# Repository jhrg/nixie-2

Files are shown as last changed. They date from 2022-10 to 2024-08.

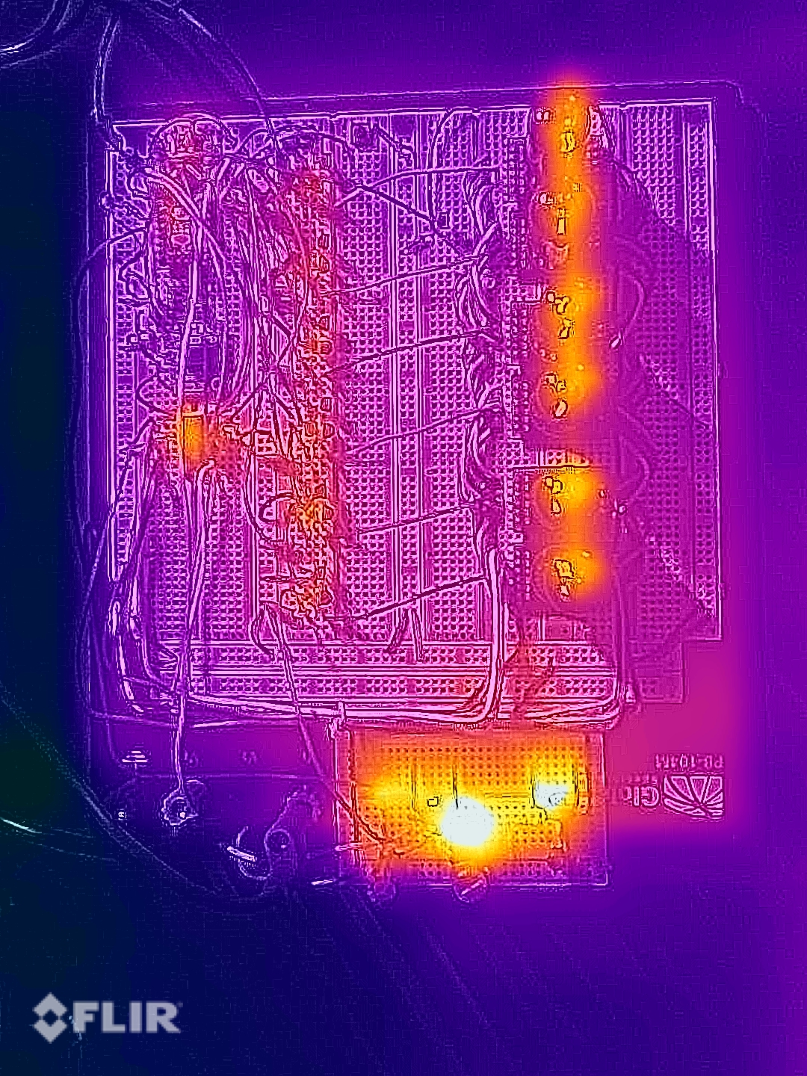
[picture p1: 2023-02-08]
docs/Nixie_FLIR_Pictures/Top_view_1.JPG

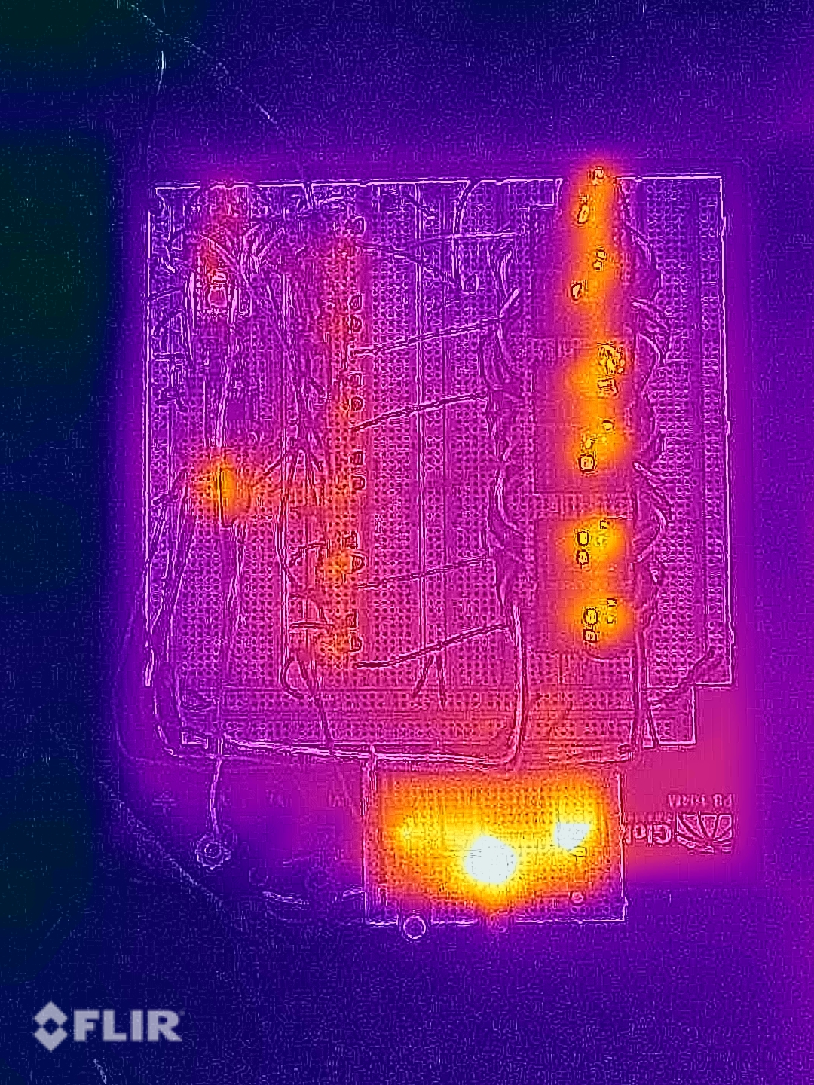
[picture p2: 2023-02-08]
docs/Nixie_FLIR_Pictures/Top_view_3.JPG

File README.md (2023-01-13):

Nixie clock code

10/1/22

The current version of this clock software is 0.1.0

A Nixie tube clock using Z573M tubes and a K155N?1 BCD to decimal driver.

This will use multiplexing to drive four Z573M tubes using one K155N?1 chip.

| Timer output | Arduino output	| Chip pin | Pin name |
|---|---|---|---|
| OC0A	 | 6	 | 12	 | PD6 |
| OC0B	 | 5	 | 11	 | PD5 |
| OC1A	 | 9	 | 15	 | PB1 |
| OC1B	 | 10	 | 16	 | PB2 |
| OC2A	 | 11	 | 17	 | PB3 |
| OC2B	 | 3	 | 5	 | PD3 |

*https://docs.arduino.cc/tutorials/generic/secrets-of-arduino-pwm

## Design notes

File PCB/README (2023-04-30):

What's here?

Z573M-tube is a breakout board for the Z57xM nixie tubes.

breakout-boards are KiCAD footprints for the Adafruit DS3231, BMP-180/280
and the exixe IN-14N nixie tube board.

nixies-2.1 has the KiCAD design files for the nixie-2.1 board

nixie-footprints.pretty holds a number of KiCAD footprints for the
nixie-2.1 PCB.

nixie-tube-clock-2.1.kicad_sym holds (most of) the symbols used by the
nixies-2.1 board.

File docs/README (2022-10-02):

Images from a scope showing the affect (good) of adding a 220K
resistor to the anode switching circuit. This decresed the time to the
off state from ~260us to 172us. It's hard to know if this is really an
improvement since the Anode voltage drops below Vm pretty fast in
either case. But, since the voltage drops to zero in 172us, that can
be the blanking interval. Since it looks like the anode voltage drops
below 100 in about 100us, might try that for the blanking interval.

The pictures are

Anode_10x_with_220k.png: The anode voltage with the 220k shunt resistor
Anode_10x_wo_220k.png: The anode voltage without the 220k shunt resistor

Anode_on_with_1466us.png: Measuring the time the anode is on when the
code uses a on delay time of 1466us

Anode_blanking.png: Measuring the time to turn the anode off, blanking
time wa 200us and this is with the 220K resistor

Anode_switch_MPSA42_base.png: What is looks like at the base of the
MPSA42 where the Arduino triggers the Anode, without the 220K shunt on
the anode.

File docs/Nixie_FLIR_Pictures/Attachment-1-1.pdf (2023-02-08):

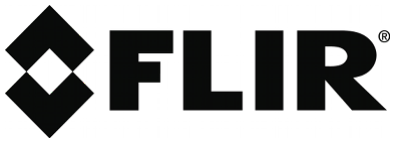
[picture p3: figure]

# PDF document

## Whole prototype top view

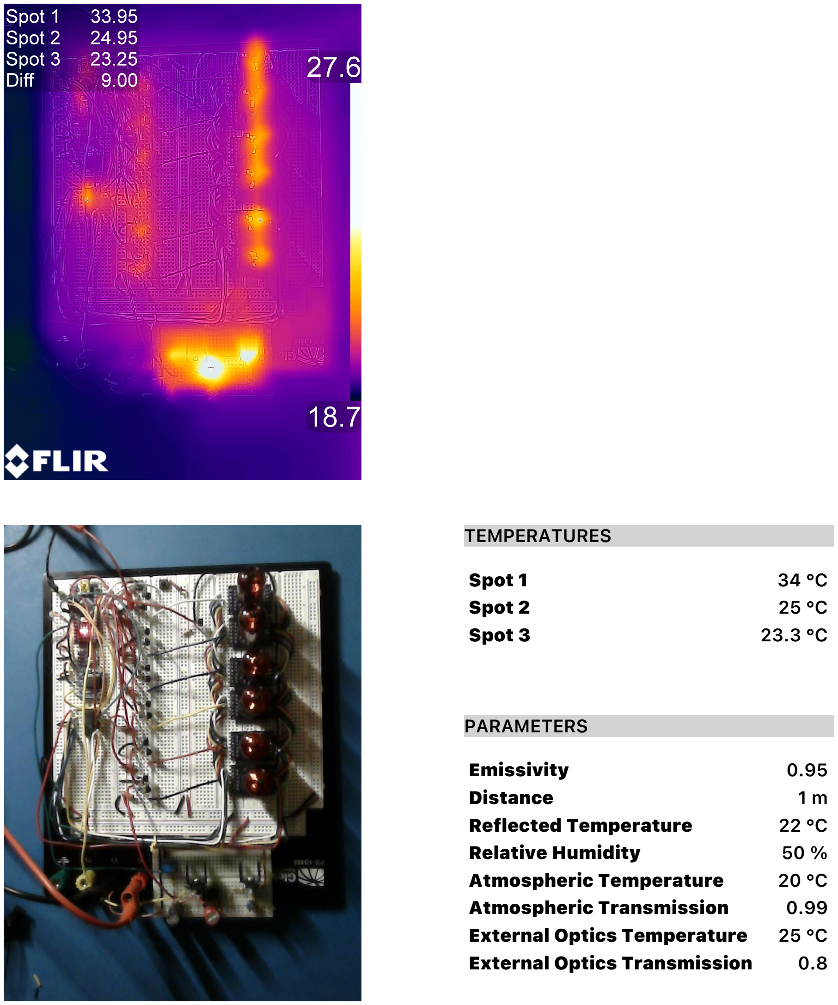
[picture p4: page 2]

TEMPERATURES

Spot 1 | 34 ℃
Spot 2 | 25 ℃
Spot 3 | 23.3 ℃

PARAMETERS

Emissivity | 0.95
Distance | 1 m
Reflected Temperature | 22 ℃
Relative Humidity | 50 %
Atmospheric Temperature | 20 ℃
Atmospheric Transmission | 0.99
External Optics Temperature | 25 ℃
External Optics Transmission | 0.8

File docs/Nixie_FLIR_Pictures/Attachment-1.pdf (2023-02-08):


# PDF document

## HV PS Close up

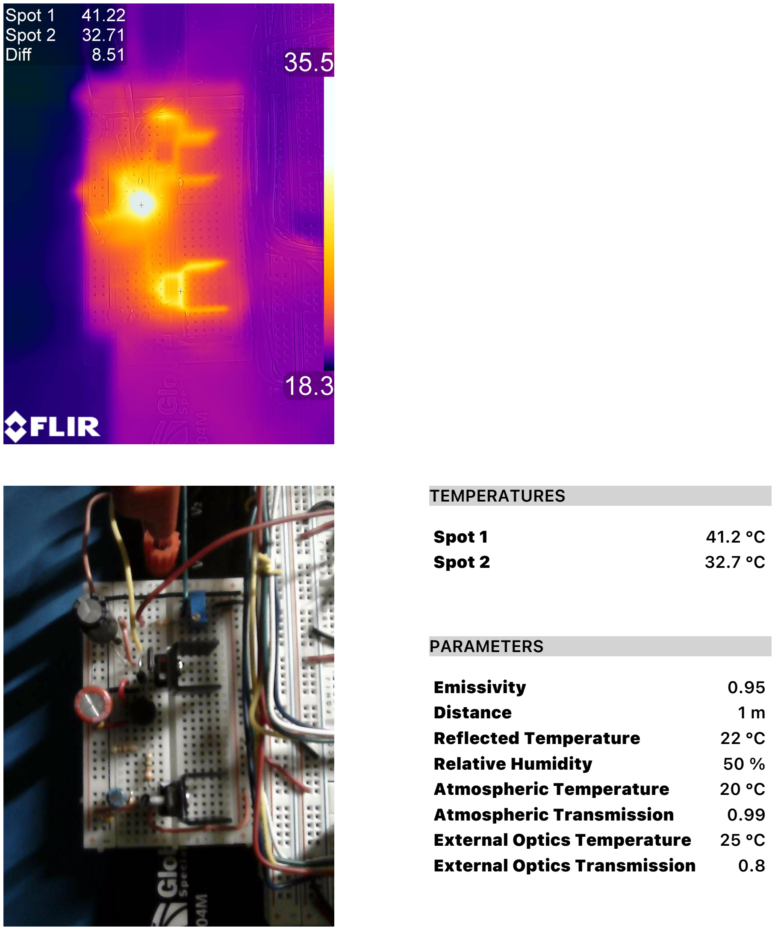
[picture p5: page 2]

TEMPERATURES

Spot 1 | 41.2 ℃
Spot 2 | 32.7 ℃

PARAMETERS

Emissivity | 0.95
Distance | 1 m
Reflected Temperature | 22 ℃
Relative Humidity | 50 %
Atmospheric Temperature | 20 ℃
Atmospheric Transmission | 0.99
External Optics Temperature | 25 ℃
External Optics Transmission | 0.8

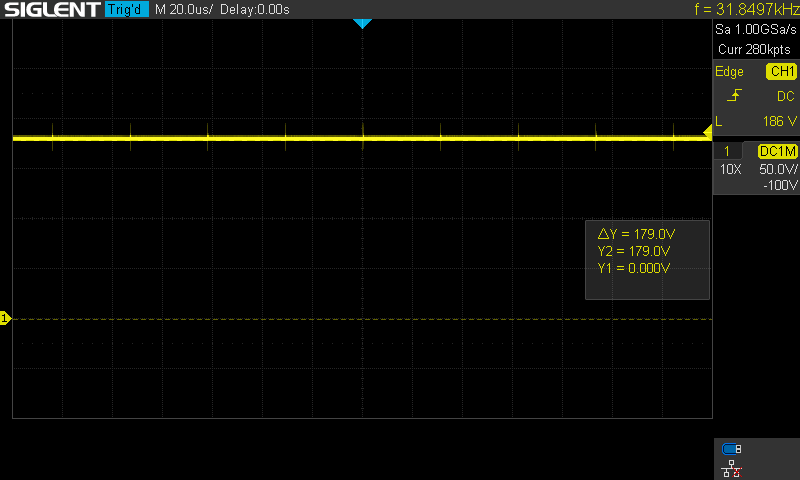
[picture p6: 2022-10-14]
docs/AVR_HV_PS/AVR_HV_PS_32kHz_no_load_10%D.png

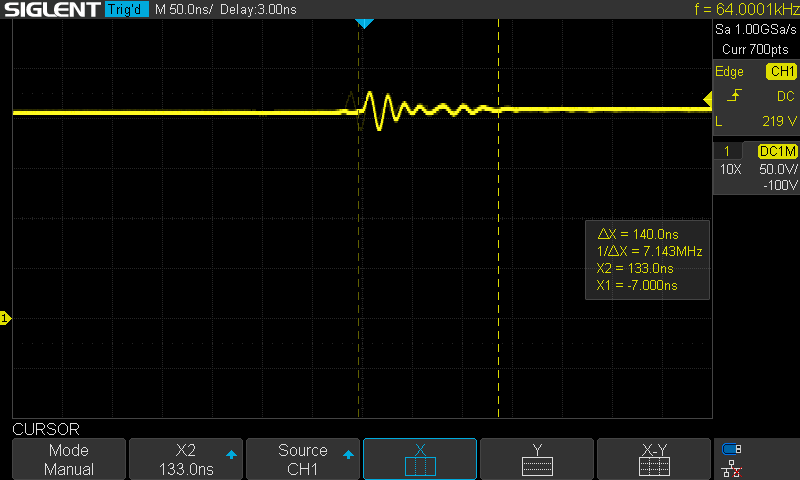
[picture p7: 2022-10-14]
docs/AVR_HV_PS/Ripple_at_64kHz.png

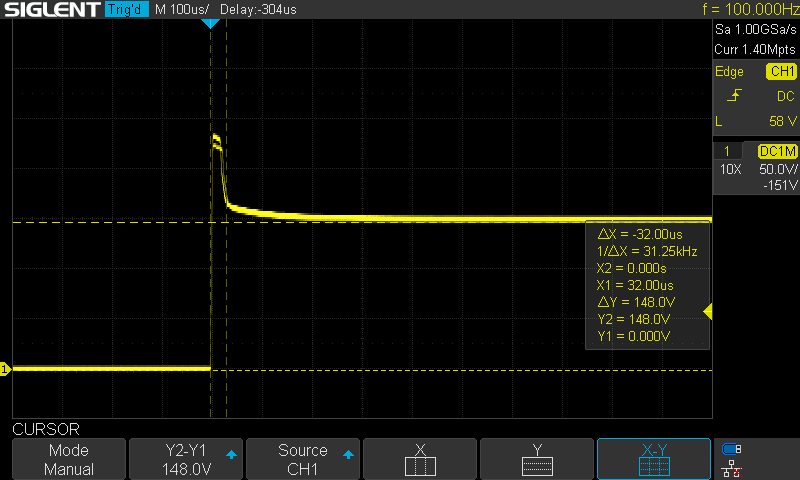
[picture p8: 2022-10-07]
docs/Ionization_time/100Hz_15k_200v_tube_voltage.png

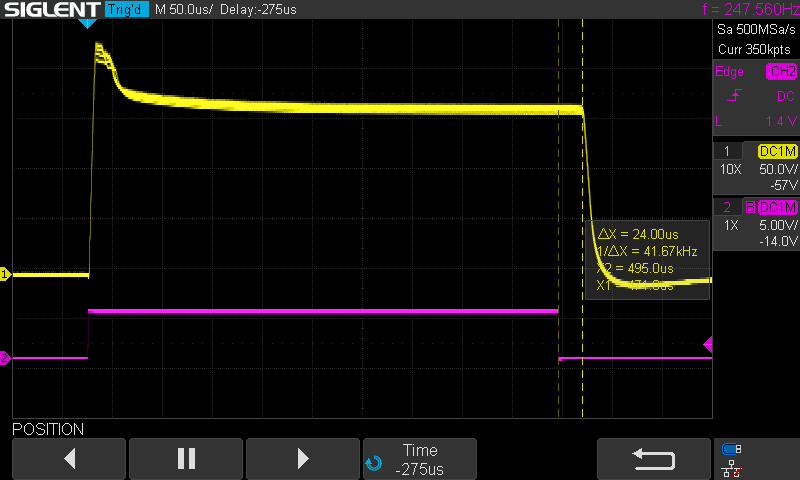
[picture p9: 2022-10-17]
docs/Anode_shunt_resistor/Tube_off_delay_24uS_with_anode_res.png

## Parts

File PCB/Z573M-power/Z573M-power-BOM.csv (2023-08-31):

Id | Designator | Footprint | Quantity | Designation | Supplier and ref
1 | H3,H2,H1 | MountingHole_3mm | 3 | MountingHole
2 | J2 | CONN3_OSTVN03A150_OST | 1 | Conn_3_screw_OSTVN03A150
3 | C4 | 10uF_400v_ESG106M400AH4AA | 1 | 10uF 400V
4 | R2,R3 | R_Axial_DIN0207_L6.3mm_D2.5mm_P7.62mm_Horizontal | 2 | 330
5 | R4 | R_Axial_DIN0207_L6.3mm_D2.5mm_P7.62mm_Horizontal | 1 | 220
6 | C6,C3,C2 | C_Disc_D5.0mm_W2.5mm_P5.00mm | 3 | 0.1uF 50V
7 | CR1 | MUR160G | 1 | MUR160G
8 | C1 | CP_Radial_D10.0mm_P5.00mm | 1 | 470uF 25V
9 | U1 | TO-220-3_Vertical | 1 | LM317_TO-220
10 | R6 | 10k_Trimmer_PV36W103C01B00 | 1 | 10K_Trimmer
11 | D3 | BZT3C240 | 1 | BZT3C240
12 | R7,R5 | R_Axial_DIN0207_L6.3mm_D2.5mm_P7.62mm_Horizontal | 2 | 390K
13 | F1 | AHRF050_30v_500mA_polyfuse | 1 | 30V 500mA
14 | D1 | D_DO-41_SOD81_P10.16mm_Horizontal | 1 | 1N5819
15 | J1 | BarrelJack_Horizontal | 1 | Barrel_Jack_Switch
16 | HS1,HS2 | AVVID-577202B-00000G | 2 | Heatsink
17 | Q1 | TO-220-3_Vertical | 1 | IRF730 TO220-3
18 | L1 | L_Radial_D7.8mm_P5.00mm_Fastron_07HCP | 1 | 200uH 1A 450m
19 | J3 | CONN_OSTVN02A150_OST | 1 | Conn_2_screw_OSTVN02A150
20 | Q2 | TO-92_HandSolder | 1 | ZTX857
21 | D2 | D_A-405_P7.62mm_Horizontal | 1 | 1N4002
22 | R1 | R_Axial_DIN0207_L6.3mm_D2.5mm_P7.62mm_Horizontal | 1 | 1M
23 | C5 | 1.0uF_160V_CAPPRD200W50D525H1250 | 1 | 1.0uF 160V

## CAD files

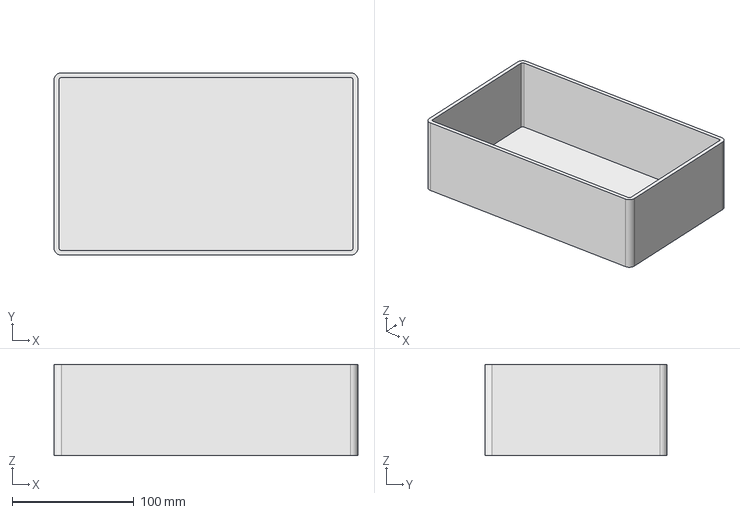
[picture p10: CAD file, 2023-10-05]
enclosure/box_2.FCStd
250.0 x 150.0 x 75.0 mm

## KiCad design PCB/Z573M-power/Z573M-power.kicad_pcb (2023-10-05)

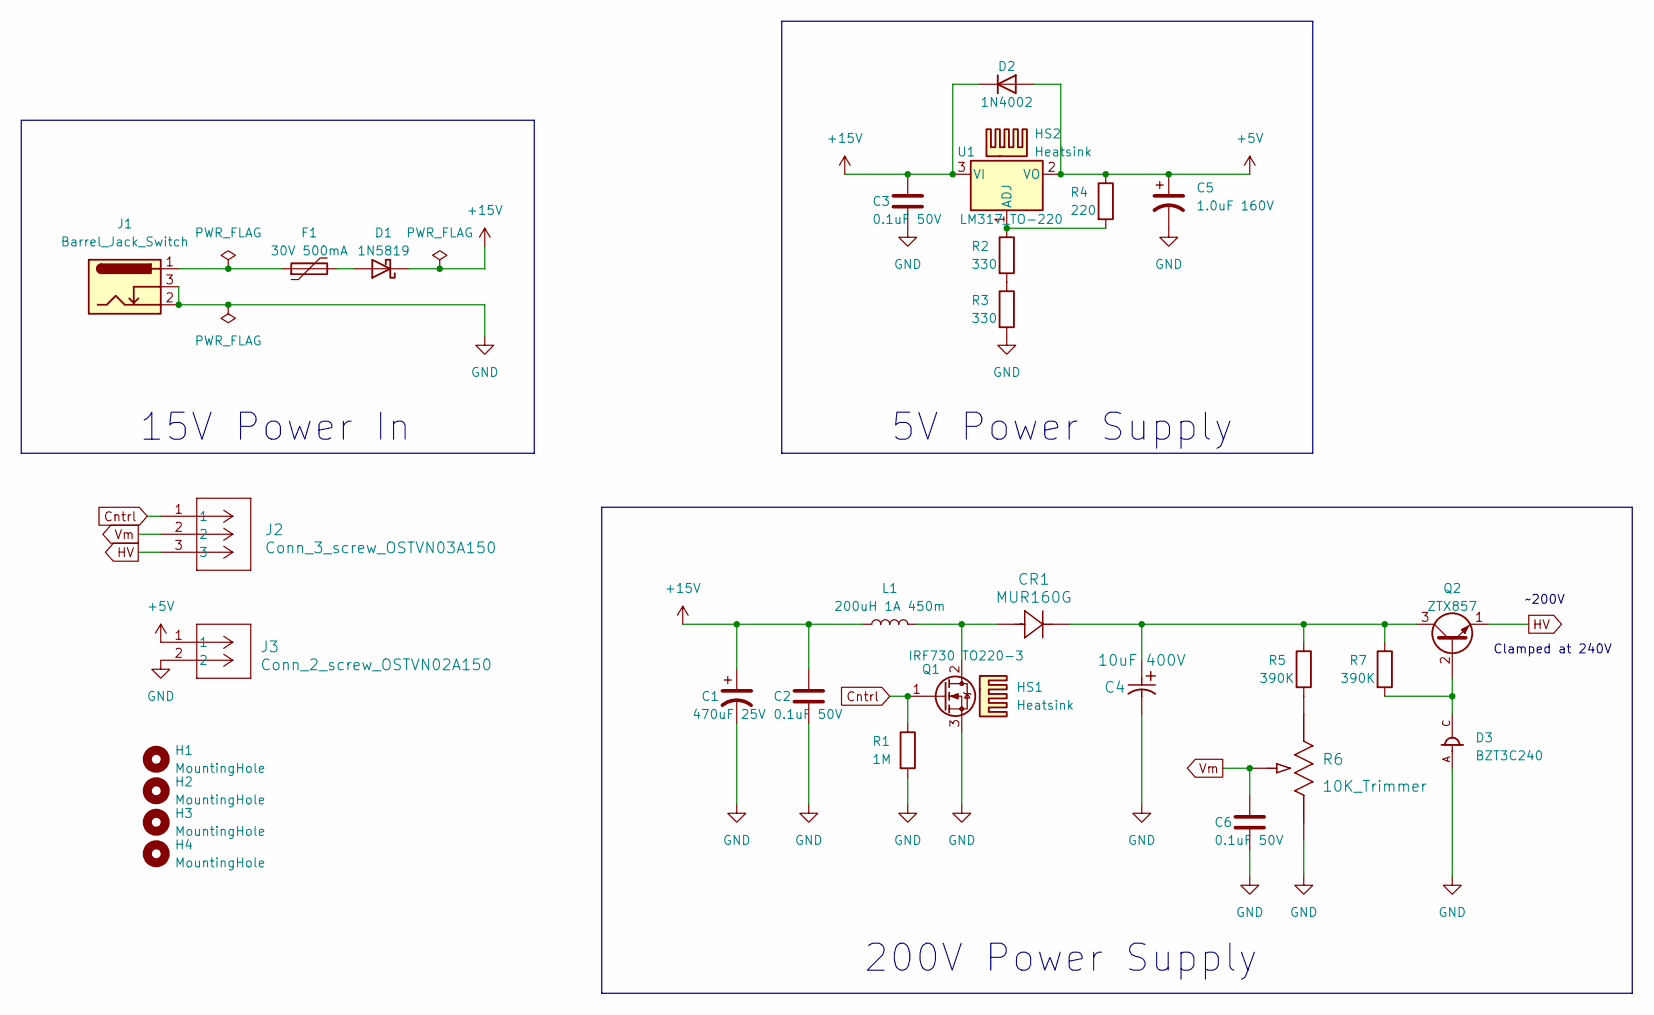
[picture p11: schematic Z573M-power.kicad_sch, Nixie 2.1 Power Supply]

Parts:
C1: 470uF 25V; CP_Radial_D10.0mm_P5.00mm
C2, C3, C6: 0.1uF 50V; C_Disc_D5.0mm_W2.5mm_P5.00mm
C4: 10uF 400V; 10uF_400v_ESG106M400AH4AA
C5: 1.0uF 160V; 1.0uF_160V_CAPPRD200W50D525H1250
CR1: MUR160G
D1: 1N5819; D_DO-41_SOD81_P10.16mm_Horizontal
D2: 1N4002; D_A-405_P7.62mm_Horizontal
D3: BZT3C240
F1: 30V 500mA; AHRF050_30v_500mA_polyfuse
H1, H2, H3, H4: MountingHole; MountingHole_3mm
HS1, HS2: Heatsink; AVVID-577202B-00000G
J1: Barrel_Jack_Switch; BarrelJack_Horizontal
J2: Conn_3_screw_OSTVN03A150; CONN3_OSTVN03A150_OST
J3: Conn_2_screw_OSTVN02A150; CONN_OSTVN02A150_OST
L1: 200uH 1A 450m; L_Radial_D7.8mm_P5.00mm_Fastron_07HCP
Q1: IRF730 TO220-3; TO-220-3_Vertical
Q2: ZTX857; TO-92_HandSolder
R1: 1M; R_Axial_DIN0207_L6.3mm_D2.5mm_P7.62mm_Horizontal
R2, R3: 330; R_Axial_DIN0207_L6.3mm_D2.5mm_P7.62mm_Horizontal
R4: 220; R_Axial_DIN0207_L6.3mm_D2.5mm_P7.62mm_Horizontal
R5, R7: 390K; R_Axial_DIN0207_L6.3mm_D2.5mm_P7.62mm_Horizontal
R6: 10K_Trimmer; 10k_Trimmer_PV36W103C01B00
U1: LM317_TO-220; TO-220-3_Vertical

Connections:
+5V: C5.1, D2.2 (A), J3.1, R4.1, U1.2 (VO)
+15V: C1.1, C2.1, C3.1, D1.1 (K), D2.1 (K), L1.1, U1.3 (VI)
Cntrl: J2.1, Q1.1 (G), R1.1
GND: C1.2, C2.2, C3.2, C4.2, C5.2, C6.2, D3.A, J1.2, J1.3, J3.2, Q1.3 (S), R1.2, R3.2, R6.1
HV: J2.3, Q2.1 (E)
unnamed: D1.2 (A), F1.2
unnamed: F1.1, J1.1
unnamed: CR1.2, L1.2, Q1.2 (D)
unnamed: D3.C, Q2.2 (B), R7.2
unnamed: C4.1, CR1.1, Q2.3 (C), R5.1, R7.1
unnamed: R2.2, R3.1
unnamed: R5.2, R6.3
unnamed: R2.1, R4.2, U1.1 (ADJ)
Vm: C6.1, J2.2, R6.2

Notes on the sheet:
5V Power Supply
~200V
200V Power Supply
15V Power In
Clamped at 240V

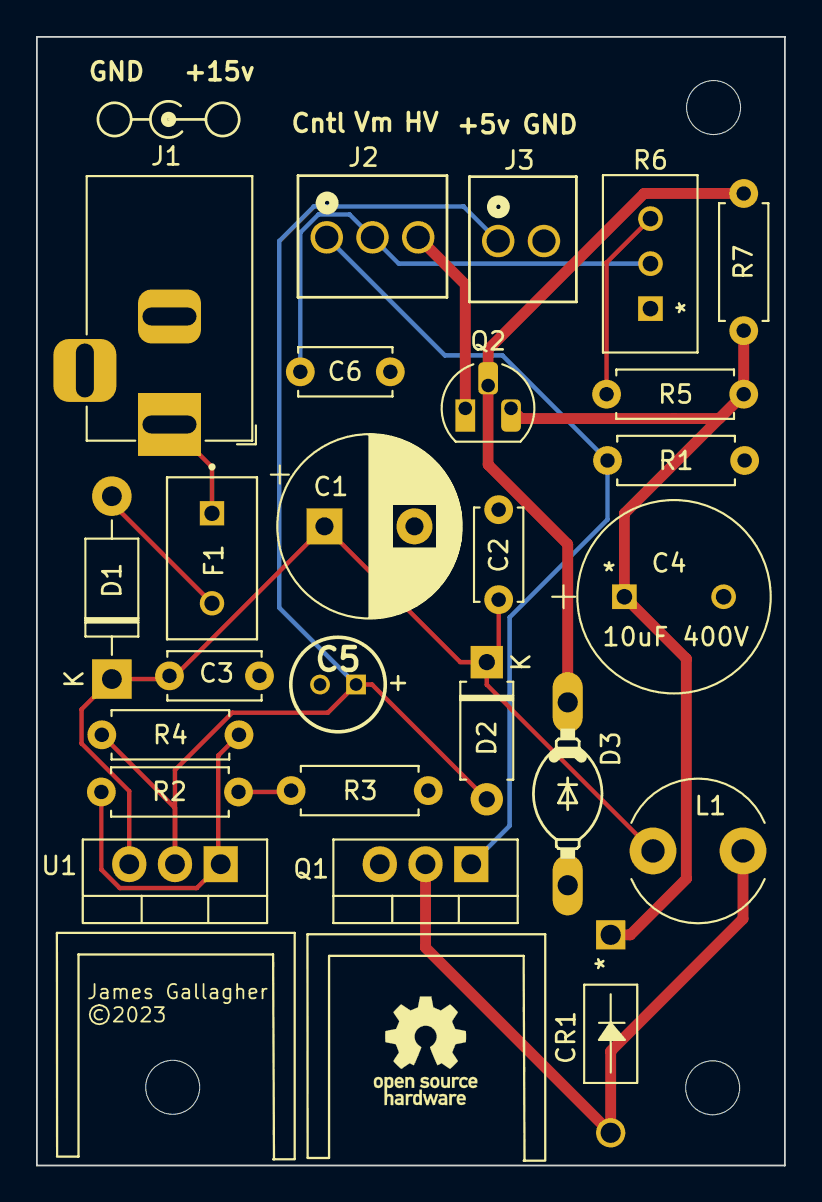
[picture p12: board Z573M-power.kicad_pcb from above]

Board: 2 copper layers, 41.6 x 62.7 mm, 30 parts (0 on the bottom side), 14 nets.

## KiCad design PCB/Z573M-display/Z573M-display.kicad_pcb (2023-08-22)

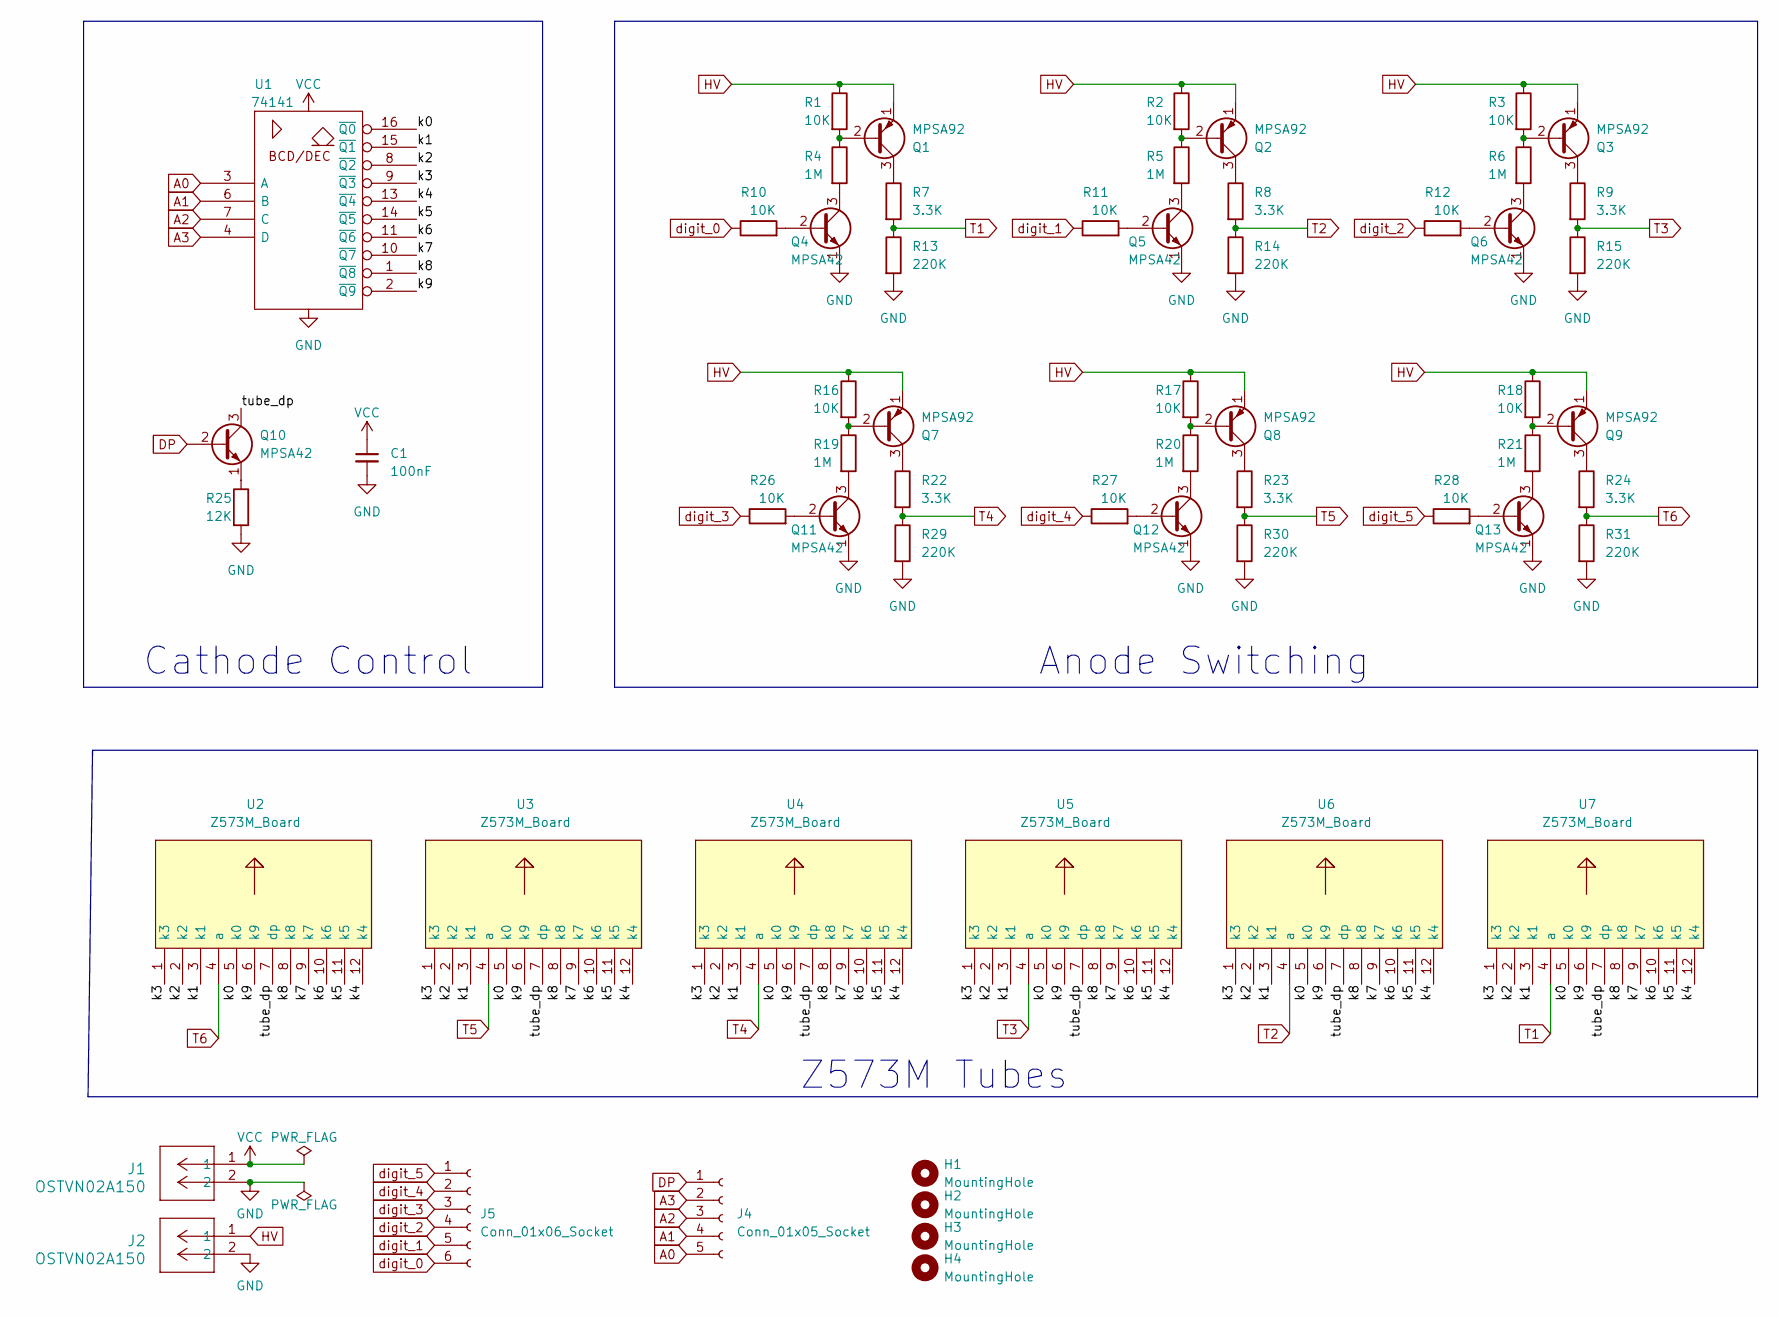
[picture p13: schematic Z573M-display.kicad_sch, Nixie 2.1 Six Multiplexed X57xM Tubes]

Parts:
C1: 100nF; C_Disc_D4.7mm_W2.5mm_P5.00mm
H1, H2, H3, H4: MountingHole; MountingHole_3mm
J1, J2: OSTVN02A150; CONN_OSTVN02A150_OST
J4: Conn_01x05_Socket; PinHeader_1x05_P2.54mm_Horizontal
J5: Conn_01x06_Socket; PinHeader_1x06_P2.54mm_Horizontal
Q1, Q2, Q3, Q7, Q8, Q9: MPSA92; TO-92_HandSolder
Q4, Q5, Q6, Q10, Q11, Q12, Q13: MPSA42; TO-92_HandSolder
R1, R2, R3, R10, R11, R12, R16, R17, R18, R26, R27, R28: 10K; R_Axial_DIN0207_L6.3mm_D2.5mm_P7.62mm_Horizontal
R4, R5, R6, R19, R20, R21: 1M; R_Axial_DIN0207_L6.3mm_D2.5mm_P7.62mm_Horizontal
R7, R8, R9, R22, R23, R24: 3.3K; R_Axial_DIN0207_L6.3mm_D2.5mm_P7.62mm_Horizontal
R13, R14, R15, R29, R30, R31: 220K; R_Axial_DIN0207_L6.3mm_D2.5mm_P7.62mm_Horizontal
R25: 12K; R_Axial_DIN0207_L6.3mm_D2.5mm_P7.62mm_Horizontal
U1: 74141; DIP-16_W7.62mm_Socket
U2, U3, U4, U5, U6, U7: Z573M_Board

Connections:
/k0: U1.16 (~Q0), U2.5 (k0), U3.5 (k0), U4.5 (k0), U5.5 (k0), U6.5 (k0), U7.5 (k0)
/k1: U1.15 (~Q1), U2.3 (k1), U3.3 (k1), U4.3 (k1), U5.3 (k1), U6.3 (k1), U7.3 (k1)
/k2: U1.8 (~Q2), U2.2 (k2), U3.2 (k2), U4.2 (k2), U5.2 (k2), U6.2 (k2), U7.2 (k2)
/k3: U1.9 (~Q3), U2.1 (k3), U3.1 (k3), U4.1 (k3), U5.1 (k3), U6.1 (k3), U7.1 (k3)
/k4: U1.13 (~Q4), U2.12 (k4), U3.12 (k4), U4.12 (k4), U5.12 (k4), U6.12 (k4), U7.12 (k4)
/k5: U1.14 (~Q5), U2.11 (k5), U3.11 (k5), U4.11 (k5), U5.11 (k5), U6.11 (k5), U7.11 (k5)
/k6: U1.11 (~Q6), U2.10 (k6), U3.10 (k6), U4.10 (k6), U5.10 (k6), U6.10 (k6), U7.10 (k6)
/k7: U1.10 (~Q7), U2.9 (k7), U3.9 (k7), U4.9 (k7), U5.9 (k7), U6.9 (k7), U7.9 (k7)
/k8: U1.1 (~Q8), U2.8 (k8), U3.8 (k8), U4.8 (k8), U5.8 (k8), U6.8 (k8), U7.8 (k8)
/k9: U1.2 (~Q9), U2.6 (k9), U3.6 (k9), U4.6 (k9), U5.6 (k9), U6.6 (k9), U7.6 (k9)
/tube_dp: Q10.3 (C), U2.7 (dp), U3.7 (dp), U4.7 (dp), U5.7 (dp), U6.7 (dp), U7.7 (dp)
A0: J4.5, U1.3 (A)
A1: J4.4, U1.6 (B)
A2: J4.3, U1.7 (C)
A3: J4.2, U1.4 (D)
DP: J4.1, Q10.2 (B)
GND: C1.2, J1.2, J2.2, Q4.1 (E), Q5.1 (E), Q6.1 (E), Q11.1 (E), Q12.1 (E), Q13.1 (E), R13.2, R14.2, R15.2, R25.2, R29.2, R30.2, R31.2, U1.12 (GND)
HV: J2.1, Q1.1 (E), Q2.1 (E), Q3.1 (E), Q7.1 (E), Q8.1 (E), Q9.1 (E), R1.1, R2.1, R3.1, R16.1, R17.1, R18.1
unnamed: Q1.2 (B), R1.2, R4.1
unnamed: Q1.3 (C), R7.1
unnamed: Q2.2 (B), R2.2, R5.1
unnamed: Q2.3 (C), R8.1
unnamed: Q3.2 (B), R3.2, R6.1
unnamed: Q3.3 (C), R9.1
unnamed: Q4.2 (B), R10.2
unnamed: Q4.3 (C), R4.2
unnamed: Q5.2 (B), R11.2
unnamed: Q5.3 (C), R5.2
unnamed: Q6.2 (B), R12.2
unnamed: Q6.3 (C), R6.2
unnamed: Q7.2 (B), R16.2, R19.1
unnamed: Q7.3 (C), R22.1
unnamed: Q8.2 (B), R17.2, R20.1
unnamed: Q8.3 (C), R23.1
unnamed: Q9.2 (B), R18.2, R21.1
unnamed: Q9.3 (C), R24.1
unnamed: Q10.1 (E), R25.1
unnamed: Q11.2 (B), R26.2
unnamed: Q11.3 (C), R19.2
unnamed: Q12.2 (B), R27.2
unnamed: Q12.3 (C), R20.2
unnamed: Q13.2 (B), R28.2
unnamed: Q13.3 (C), R21.2
T1: R7.2, R13.1, U7.4 (a)
T2: R8.2, R14.1, U6.4 (a)
T3: R9.2, R15.1, U5.4 (a)
T4: R22.2, R29.1, U4.4 (a)
T5: R23.2, R30.1, U3.4 (a)
T6: R24.2, R31.1, U2.4 (a)
VCC: C1.1, J1.1, U1.5 (VCC)
digit_0: J5.6, R10.1
digit_1: J5.5, R11.1
digit_2: J5.4, R12.1
digit_3: J5.3, R26.1
digit_4: J5.2, R27.1
digit_5: J5.1, R28.1

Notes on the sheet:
Z573M Tubes
Anode Switching
Cathode Control

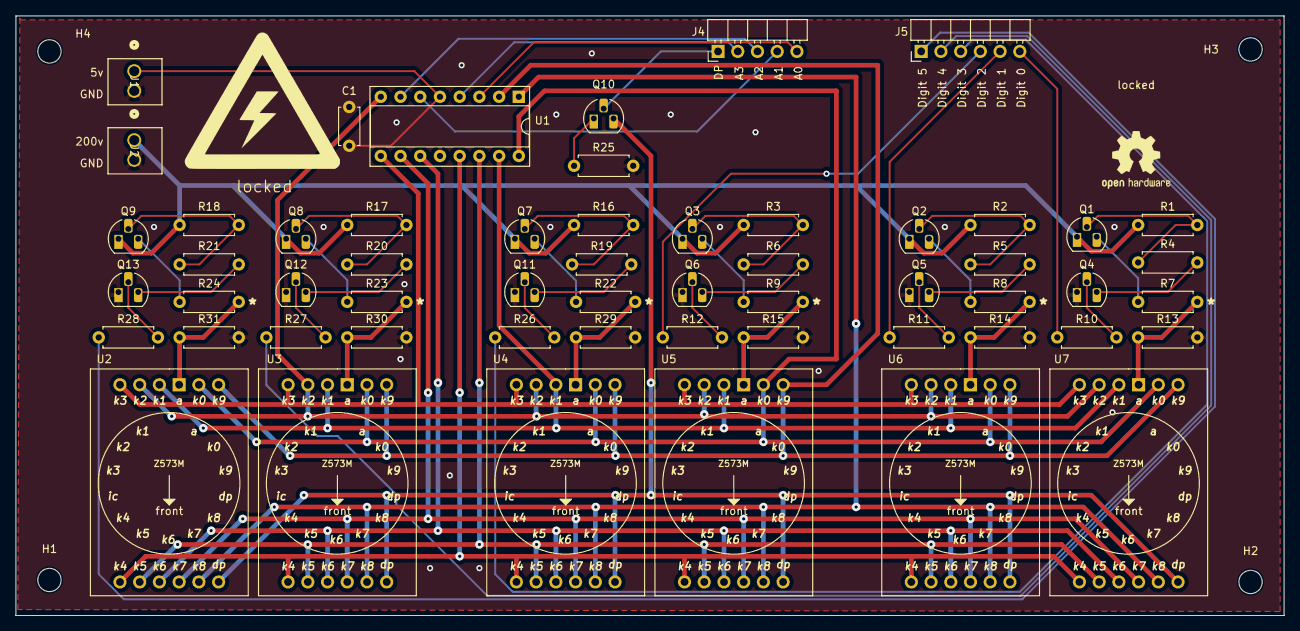
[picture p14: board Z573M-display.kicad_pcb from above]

Board: 2 copper layers, 163.3 x 77.2 mm, 60 parts (0 on the bottom side), 56 nets.

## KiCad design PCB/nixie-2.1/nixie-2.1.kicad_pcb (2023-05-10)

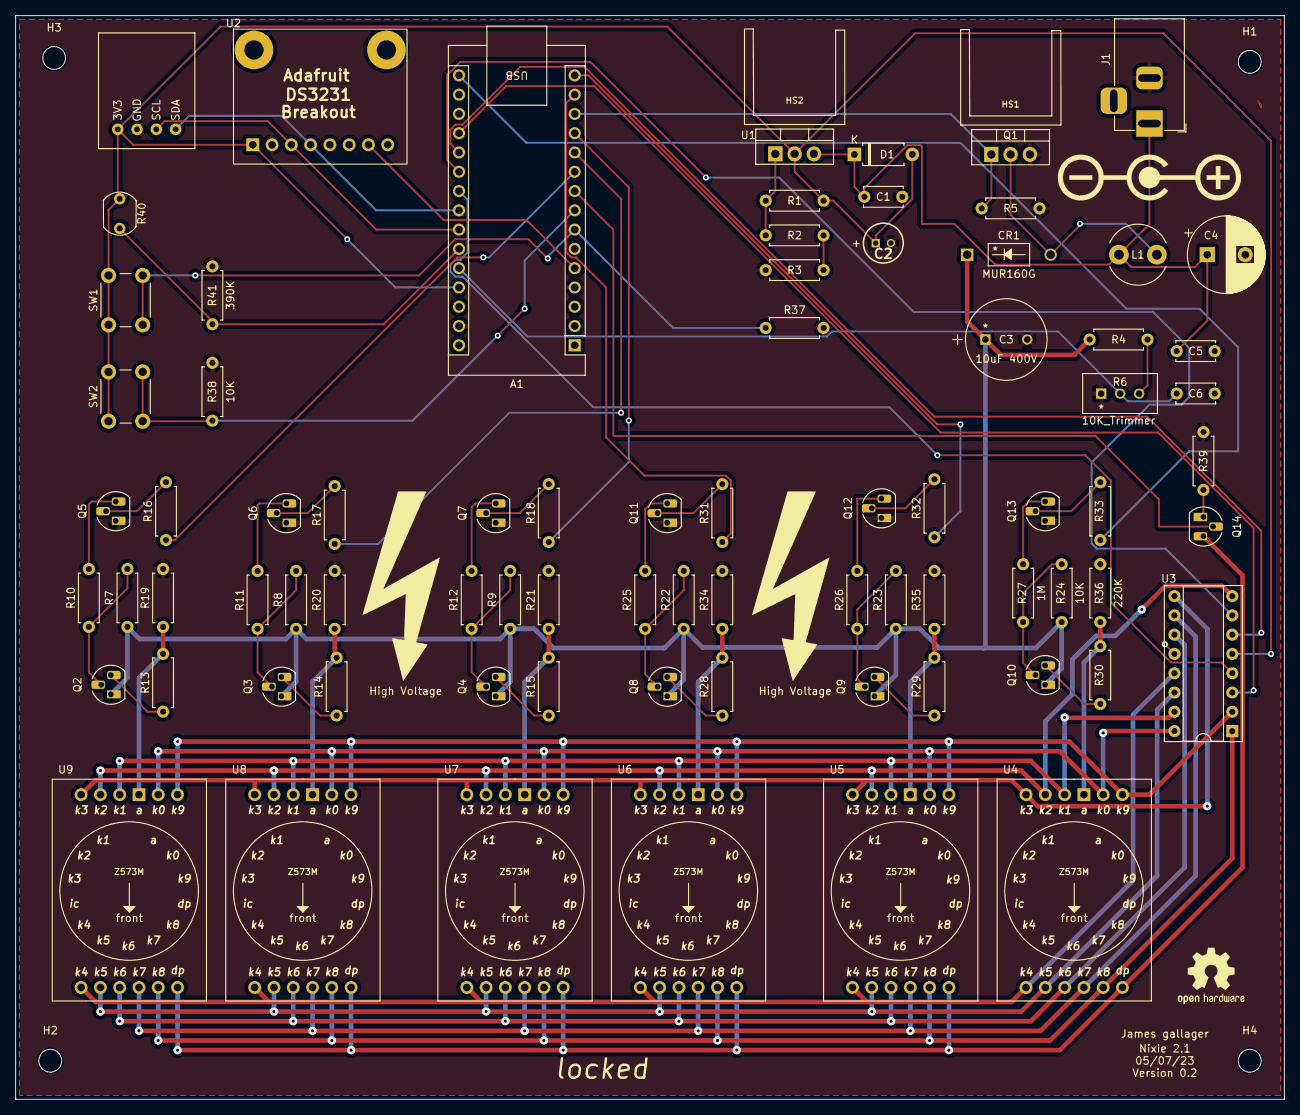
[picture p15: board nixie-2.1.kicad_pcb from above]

Board: 2 copper layers, 167.1 x 142.7 mm, 84 parts (0 on the bottom side), 69 nets.

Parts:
A1: Arduino_Nano_v3.x; Arduino_Nano
C1, C5, C6: 0.1uF 50V; C_Disc_D5.0mm_W2.5mm_P5.00mm
C2: 1.0uF 160V; 1.0uF_160V_CAPPRD200W50D525H1250
C3: 10uF 400V; ESG475M400AH2AA
C4: 470uF 25V; CP_Radial_D10.0mm_P5.00mm
CR1: MUR160G
D1: 1N4002; D_A-405_P7.62mm_Horizontal
H1, H2, H3, H4: MountingHole; MountingHole_3mm
HS1, HS2: Heatsink; AVVID-577202B-00000G
J1: Barrel_Jack_Switch; BarrelJack_Horizontal
L1: 200uH 1A 450m; L_Radial_D7.8mm_P5.00mm_Fastron_07HCP
Q1: IRF730 TO220-3; TO-220-3_Vertical
Q2, Q3, Q4, Q8, Q9, Q10: MPSA92; TO-92_HandSolder
Q5, Q6, Q7, Q11, Q12, Q13, Q14: MPSA42; TO-92_HandSolder
R1: 220; R_Axial_DIN0207_L6.3mm_D2.5mm_P7.62mm_Horizontal
R2, R3: 330; R_Axial_DIN0207_L6.3mm_D2.5mm_P7.62mm_Horizontal
R4, R41: 390K; R_Axial_DIN0207_L6.3mm_D2.5mm_P7.62mm_Horizontal
R5, R10, R11, R12, R25, R26, R27: 1M; R_Axial_DIN0207_L6.3mm_D2.5mm_P7.62mm_Horizontal
R6: 10K_Trimmer; PV36W103C01B00
R7, R8, R9, R16, R17, R18, R22, R23, R24, R31, R32, R33, R37, R38: 10K; R_Axial_DIN0207_L6.3mm_D2.5mm_P7.62mm_Horizontal
R13, R14, R15, R28, R29, R30: 3.3K; R_Axial_DIN0207_L6.3mm_D2.5mm_P7.62mm_Horizontal
R19, R20, R21, R34, R35, R36: 220K; R_Axial_DIN0207_L6.3mm_D2.5mm_P7.62mm_Horizontal
R39: 12K; R_Axial_DIN0207_L6.3mm_D2.5mm_P7.62mm_Horizontal
R40: R_Photo; R_LDR_5.1x4.3mm_P3.9mm_Vertical
SW1, SW2: SW_Push; SW_PUSH_6mm
U1: LM317_TO-220; TO-220-3_Vertical
U2: Adafruit_DS3231_breakout
U3: 74141; DIP-16_W7.62mm_Socket
U4, U5, U6, U7, U8, U9: Z573M_Board
U10: BMP180_breakout; BMP280_bb

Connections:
1s_pulse: A1.5 (D2), U2.7 (SQW)
+5V: A1.27 (+5V), C2.1, D1.2 (A), R1.1, R40.1, SW1.1, SW2.1, U1.2 (VO), U2.1 (Vin), U3.5 (VCC), U10.1 (Vin)
+15V: C1.1, C4.1, C5.1, D1.1 (K), J1.1, L1.1, U1.3 (VI)
/Nixies 2.1 Display/k0: U3.16 (~Q0), U4.5 (k0), U5.5 (k0), U6.5 (k0), U7.5 (k0), U8.5 (k0), U9.5 (k0)
/Nixies 2.1 Display/k1: U3.15 (~Q1), U4.3 (k1), U5.3 (k1), U6.3 (k1), U7.3 (k1), U8.3 (k1), U9.3 (k1)
/Nixies 2.1 Display/k2: U3.8 (~Q2), U4.2 (k2), U5.2 (k2), U6.2 (k2), U7.2 (k2), U8.2 (k2), U9.2 (k2)
/Nixies 2.1 Display/k3: U3.9 (~Q3), U4.1 (k3), U5.1 (k3), U6.1 (k3), U7.1 (k3), U8.1 (k3), U9.1 (k3)
/Nixies 2.1 Display/k4: U3.13 (~Q4), U4.12 (k4), U5.12 (k4), U6.12 (k4), U7.12 (k4), U8.12 (k4), U9.12 (k4)
/Nixies 2.1 Display/k5: U3.14 (~Q5), U4.11 (k5), U5.11 (k5), U6.11 (k5), U7.11 (k5), U8.11 (k5), U9.11 (k5)
/Nixies 2.1 Display/k6: U3.11 (~Q6), U4.10 (k6), U5.10 (k6), U6.10 (k6), U7.10 (k6), U8.10 (k6), U9.10 (k6)
/Nixies 2.1 Display/k7: U3.10 (~Q7), U4.9 (k7), U5.9 (k7), U6.9 (k7), U7.9 (k7), U8.9 (k7), U9.9 (k7)
/Nixies 2.1 Display/k8: U3.1 (~Q8), U4.8 (k8), U5.8 (k8), U6.8 (k8), U7.8 (k8), U8.8 (k8), U9.8 (k8)
/Nixies 2.1 Display/k9: U3.2 (~Q9), U4.6 (k9), U5.6 (k9), U6.6 (k9), U7.6 (k9), U8.6 (k9), U9.6 (k9)
/Nixies 2.1 Display/tube_dp: Q14.3 (C), U4.7 (dp), U5.7 (dp), U6.7 (dp), U7.7 (dp), U8.7 (dp), U9.7 (dp)
A0: A1.19 (A0), U3.3 (A)
A1: A1.20 (A1), U3.6 (B)
A2: A1.21 (A2), U3.7 (C)
A3: A1.22 (A3), U3.4 (D)
Cntrl: A1.13 (D10), Q1.1 (G), R5.1
DP: A1.9 (D6), Q14.2 (B)
GND: A1.4 (GND), A1.29 (GND), C1.2, C2.2, C3.2, C4.2, C5.2, C6.2, J1.2, Q1.3 (S), Q5.1 (E), Q6.1 (E), Q7.1 (E), Q11.1 (E), Q12.1 (E), Q13.1 (E), R3.2, R5.2, R6.1, R19.2, R20.2, R21.2, R34.2, R35.2, R36.2, R37.2, R38.2, R39.2, R41.2, U2.2 (GND), U3.12 (GND), U10.2 (GND)
HV: C3.1, CR1.1, Q2.1 (E), Q3.1 (E), Q4.1 (E), Q8.1 (E), Q9.1 (E), Q10.1 (E), R4.1, R7.1, R8.1, R9.1, R22.1, R23.1, R24.1
unnamed: A1.25 (A6), R40.2, R41.1
unnamed: A1.7 (D4), R37.1, SW1.2
unnamed: A1.8 (D5), R38.1, SW2.2
unnamed: CR1.2, L1.2, Q1.2 (D)
unnamed: Q2.2 (B), R7.2, R10.1
unnamed: Q2.3 (C), R13.1
unnamed: Q3.2 (B), R8.2, R11.1
unnamed: Q3.3 (C), R14.1
unnamed: Q4.2 (B), R9.2, R12.1
unnamed: Q4.3 (C), R15.1
unnamed: Q5.2 (B), R16.2
unnamed: Q5.3 (C), R10.2
unnamed: Q6.2 (B), R17.2
unnamed: Q6.3 (C), R11.2
unnamed: Q7.2 (B), R18.2
unnamed: Q7.3 (C), R12.2
unnamed: Q8.2 (B), R22.2, R25.1
unnamed: Q8.3 (C), R28.1
unnamed: Q9.2 (B), R23.2, R26.1
unnamed: Q9.3 (C), R29.1
unnamed: Q10.2 (B), R24.2, R27.1
unnamed: Q10.3 (C), R30.1
unnamed: Q11.2 (B), R31.2
unnamed: Q11.3 (C), R25.2
unnamed: Q12.2 (B), R32.2
unnamed: Q12.3 (C), R26.2
unnamed: Q13.2 (B), R33.2
unnamed: Q13.3 (C), R27.2
unnamed: Q14.1 (E), R39.1
unnamed: R2.2, R3.1
unnamed: R4.2, R6.3
unnamed: R1.2, R2.1, U1.1 (ADJ)
SCL: A1.24 (A5), U2.3 (SCL), U10.3 (SCL)
SDA: A1.23 (A4), U2.4 (SDA), U10.4 (SDA)
T1: R13.2, R19.1, U9.4 (a)
T2: R14.2, R20.1, U8.4 (a)
T3: R15.2, R21.1, U7.4 (a)
T4: R28.2, R34.1, U6.4 (a)
T5: R29.2, R35.1, U5.4 (a)
T6: R30.2, R36.1, U4.4 (a)
Vm: A1.26 (A7), C6.1, R6.2
digit_0: A1.10 (D7), R16.1
digit_1: A1.11 (D8), R17.1
digit_2: A1.12 (D9), R18.1
digit_3: A1.14 (D11), R31.1
digit_4: A1.15 (D12), R32.1
digit_5: A1.16 (D13), R33.1

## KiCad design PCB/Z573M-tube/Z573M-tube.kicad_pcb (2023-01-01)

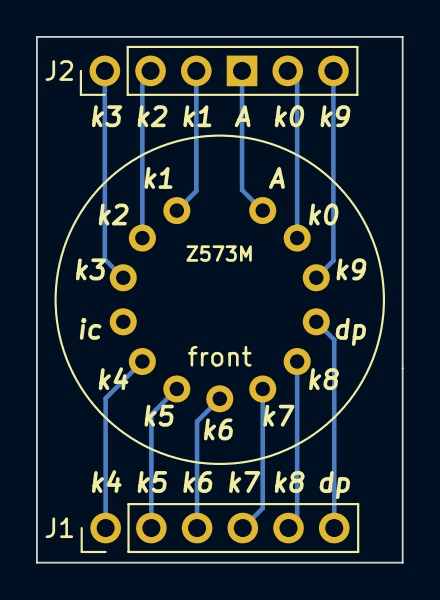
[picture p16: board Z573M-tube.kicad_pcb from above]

Board: 2 copper layers, 20.3 x 29.2 mm, 3 parts (0 on the bottom side), 12 nets.

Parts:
J1, J2: 6-pin-header; PinHeader_1x06_P2.54mm_Vertical
Version 2.0: Z57xM; Z57xM-v3-HV

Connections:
/A: J2.4, Version 2.0.13 (A)
/K0: J2.5, Version 2.0.12 (K0)
/K1: J2.3, Version 2.0.1 (K1)
/K2: J2.2, Version 2.0.2 (K2)
/K3: J2.1, Version 2.0.3 (K3)
/K4: J1.1, Version 2.0.5 (K4)
/K5: J1.2, Version 2.0.6 (K5)
/K6: J1.3, Version 2.0.7 (K6)
/K7: J1.4, Version 2.0.8 (K7)
/K8: J1.5, Version 2.0.9 (K8)
/K9: J2.6, Version 2.0.11 (K9)
/KPR: J1.6, Version 2.0.10 (KPR)

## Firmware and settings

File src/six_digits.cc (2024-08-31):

/*
  Six digit clock.

  10/1/22 jhrg
*/

#include <Arduino.h>
#include <PinChangeInterrupt.h>
#include <RTClib.h> // https://github.com/adafruit/RTClib

#include "hv_ps.h"
#include "met_sensor.h"
#include "mode_switch.h"
#include "ambient_light.h"
#include "print.h"

extern volatile enum modes mode;
extern volatile enum main_modes main_mode;

#define BAUD_RATE 115200        // old: 9600
#define CLOCK_QUERY_INTERVAL 12 // seconds

#define CLOCK_1HZ 2 // D2

// This is PORTC (bits 0 to 3; 4 & 5 are for the I2C bus)
#define BCD_A A0
#define BCD_B A1
#define BCD_C A2
#define BCD_D A3

// BCD codes for the digits 0 to 9. Only uses the low nyble
uint8_t bcd[10] = {
    B00000000,
    B00000001,
    B00000010,
    B00000011,
    B00000100,
    B00000101,
    B00000110,
    B00000111,
    B00001000,
    B00001001};

// PORTD, the decimal points and digit 0
#define RHDP B01000000    // D6 (Port D)
#define DIGIT_0 B10000000 // Pin 7 (Port D)

// All of the remaining digits are on PORTB (D8 - D15).
#define DIGIT_1 B00000001 // Pin 8 (Port B)
#define DIGIT_2 B00000010 // Pin 9
#define DIGIT_3 B00001000 // Pin 11
#define DIGIT_4 B00010000 // Pin 12
#define DIGIT_5 B00100000 // Pin 13

RTC_DS3231 rtc;
extern Adafruit_BME280 bme;

// The state machine for the display multiplexing
volatile bool blanking;
volatile int digit;

// The current display digits
volatile int digit_0;
volatile int digit_1;
volatile int digit_2;
volatile int digit_3;
volatile int digit_4;
volatile int digit_5;

volatile int d0_rhdp;
volatile int d1_rhdp;
volatile int d2_rhdp;
volatile int d3_rhdp;
volatile int d4_rhdp;
volatile int d5_rhdp;

/**
 * Print the values of the current digits
 */
void print_digits(bool newline) {
#if DEBUG
    print("%01d-%01d-%01d-%01d-%01d-%01d\n", digit_5, digit_4, digit_3, digit_2, digit_1, digit_0);
#endif
}

/**
 * Print the current time, formatted
 */
void print_time(DateTime dt, bool print_newline = false) {
#if DEBUG
    // or Serial.println(now.toString(buffer));, buffer == YY/MM/DD hh:mm:ss
    print("%02d/%02d/%02d %02d:%02d:%02d", dt.year(), dt.month(), dt.day(), dt.hour(), dt.minute(), dt.second());
    if (print_newline)
        print("\n");
#endif
}

// The global value of time - enables advancing time without I2C use. This
// is global so the value set in setup() will be available initially in the loop().
//
// DateTime cannot be 'volatile' given its definition
DateTime dt;

void update_display_with_time() {
    digit_0 = dt.second() % 10;
    digit_1 = dt.second() / 10;

    digit_2 = dt.minute() % 10;
    digit_3 = dt.minute() / 10;

    digit_4 = dt.hour() % 10;
    digit_5 = dt.hour() / 10;
}

// mm/dd/yy
void update_display_with_date() {
    digit_0 = dt.year() % 10;
    digit_1 = (dt.year() - 2000) / 10;

    digit_2 = dt.day() % 10;
    digit_3 = dt.day() / 10;

    digit_4 = dt.month() % 10;
    digit_5 = dt.month() / 10;
}

void update_display_using_mode() {
    static bool blinker = false; // blink dp for date

    switch (main_mode) {
    case show_time:
        update_display_with_time();
        break;

    case show_date:
        blinker = !blinker;
        d0_rhdp = blinker ? 1 : 0;
        update_display_with_date();
        break;

    case show_weather: {
        update_display_with_weather();
        break;
    }

    default:
        break;
    }
}

void blank_dp() {
    d0_rhdp = 0;
    d1_rhdp = 0;
    d2_rhdp = 0;
    d3_rhdp = 0;
    d4_rhdp = 0;
    d5_rhdp = 0;
}

// Set HIGH when the CLOCK_QUERY_INTERVAL seconds have elapsed and
// the RTC should be accessed.
volatile bool get_time = false;

// Set HIGH when the 1 second interrupt been triggered by the clock,
// Used in main_mode_handler()
volatile bool update_display = false;

/**
 * @brief Record that one second has elapsed
 */
void timer_1HZ_tick_ISR() {
    static volatile int tick_count = 0;

    tick_count++;

    if (tick_count >= CLOCK_QUERY_INTERVAL) {
        // update time using I2C access to the clock
        tick_count = 0;
        get_time = true;
    }

    // when get_time is false, main_mode_handler() adds one second to the global
    // time (dt) when update_display is true.
    update_display = true;
}

/**
 * Set brightness by varying the digit on and off time.
 *
 * 900us, ..., 0+ with the off time being 100us, ..., 1000us
 * With the pre-scalar at 64, a count of 0 is 4uS, 1 is 8uS, ...,
 * For example: 224 = [(16*10^6 / 64 ) * 0.000 900] - 1; (must be <256)
 *
 * There are six brightness levels 0-5 and the counter values for the on and
 * off times are precomputed and used via the arrays below. The brightness
 * level is held in the following global that can be set by the input button
 * (see set_mode.cc). The default/initial value is 0 which is the brightest
 * level.
 */
volatile int brightness = 0;

const int brightness_count[] = {231, 179, 128, 76, 24, 10}; // ~900us, ...
const int blanking_count[] = {24, 76, 127, 179, 231, 245}; // 100us, ...

/**
 * How the pair_n variables are used: If any one of these values is zero, that
 * means 1. the clock in the the set_date_time_mode and 2. brightness is 0 - the
 * brightest setting. For any of the digit pairs that have pair_n == 0, drop the
 * brightness of that pair by BRIGHTNESS_REDUCTION, which will show that the bright 
 * digit pair is the one being set and the dimmer ones, not.
 */
volatile bool pair_0 = true;
volatile bool pair_1 = true;
volatile bool pair_2 = true;

#define BRIGHTNESS_REDUCTION 3

/**
 * @brief The display multiplexing code. A simple state-machine
 *
 * The state variable blanking describes the current state, so when blanking,
 * light a digit and make the state non-blanking.
 */
ISR(TIMER2_COMPA_vect) {
    // See https://www.nongnu.org/avr-libc/user-manual/group__avr__interrupts.html
#if TIMER_INTERRUPT_DIAGNOSTIC
    PORTD |= _BV(PORTD3);
#endif

    // If the current state is blanking, stop blanking and enter digit display state
    // From the scope, when blanking is true, time in this code is 5us
    if (blanking) {
        switch (digit) {
        case 0:
            //  Set the BCD value on A0-A3. Preserve the values of A4-A7
            PORTC &= B11110000;

            // use a digit value of -1 for blanking
            if (digit_0 > -1) {
                PORTC |= bcd[digit_0];

                // Turn on the digit, The digits are blanked below during the blanking state
                PORTD |= DIGIT_0;

                // Turn on the decimal point(s) if set
                if (d0_rhdp)
                    PORTD |= RHDP;

                OCR2A = (pair_0) ? brightness_count[brightness] : brightness_count[BRIGHTNESS_REDUCTION];
            }
            // move the state to the next digit
            digit += 1;
            break;

        case 1:
            PORTC &= B11110000;
            if (digit_1 > -1) {
                PORTC |= bcd[digit_1];
                PORTB |= DIGIT_1;
                if (d1_rhdp)
                    PORTD |= RHDP;
                OCR2A = (pair_0) ? brightness_count[brightness] : brightness_count[BRIGHTNESS_REDUCTION];
            }
            digit += 1;
            break;

        case 2:
            PORTC &= B11110000;
            if (digit_2 > -1) {
                PORTC |= bcd[digit_2];
                PORTB |= DIGIT_2;
                if (d2_rhdp)
                    PORTD |= RHDP;
                OCR2A = (pair_1) ? brightness_count[brightness] : brightness_count[BRIGHTNESS_REDUCTION];
            }

            digit += 1;
            break;

        case 3:
            PORTC &= B11110000;
            if (digit_3 > -1) {
                PORTC |= bcd[digit_3];
                PORTB |= DIGIT_3;
                if (d3_rhdp)
                    PORTD |= RHDP;
                OCR2A = (pair_1) ? brightness_count[brightness] : brightness_count[BRIGHTNESS_REDUCTION];
            }
            digit += 1;
            break;

        case 4:
            PORTC &= B11110000;
            if (digit_4 > -1) {
                PORTC |= bcd[digit_4];
                PORTB |= DIGIT_4;
                if (d4_rhdp)
                    PORTD |= RHDP;
                OCR2A = (pair_2) ? brightness_count[brightness] : brightness_count[BRIGHTNESS_REDUCTION];
            }
            digit += 1;
            break;

        case 5:
            PORTC &= B11110000;
            if (digit_5 > -1) {
                PORTC |= bcd[digit_5];
                PORTB |= DIGIT_5;
                if (d5_rhdp)
                    PORTD |= RHDP;
                OCR2A = (pair_2) ? brightness_count[brightness] : brightness_count[BRIGHTNESS_REDUCTION];
            }
            digit = 0;
            break;
        }

        // State is not blanking
        blanking = false;

        // Set the timer to illuminate the digit (e.g., for 900uS)
        // OCR2A = brightness_count[brightness];
    } else {
        // blank_display
        PORTB &= B11000100;
        PORTD &= B00111111;

        // State is blanking
        blanking = true;

        // Set the timer to blank for, e.g., 100uS. See above
        OCR2A = blanking_count[brightness];
    }

#if TIMER_INTERRUPT_DIAGNOSTIC
    PORTD &= ~_BV(PORTD3);
#endif
}

void setup() {
// Enable some minor, chatty, messages on the serial line.
#if DEBUG
    Serial.begin(BAUD_RATE);
#endif
    DPRINT("boot\n");

    // Initialize all I/O pins to output, then set up the inputs/interrupts
    DDRD = B11111111; // D0 - D7
    DDRC = B00111111; // A0 - A5, bit 6 is RST, 7 is undefined
    DDRB = B00111111; // D8 - D13, bits 6,7 are for the crystal

    // Initialize all GPIO pins to LOW
    PORTD = B00000000;
    PORTC = B00000000;
    PORTB = B00000000;

    Wire.begin();

    if (rtc.begin()) {
        DPRINT("DS3131 RTC Start\n");
    } else {
        DPRINT("Couldn't find RTC\n");
        // TODO Set error flag
    }

    if (init_bme280()) {
        DPRINT("BME280 Start\n");
    } else {
        DPRINT("Couldn't setup BME280\n");
        // TODO Set error flag
    }

#if ADJUST_TIME
    // Run this here, before serial configuration to shorten the delay
    // between the compiled-in times and the set operation.
    Serial.print("Build date: ");
    Serial.println(__DATE__);
    Serial.print("Build time: ");
    Serial.println(__TIME__);

    DateTime build_time = DateTime(F(__DATE__), F(__TIME__));
    TimeSpan ts(ADJUST_TIME);
    build_time = build_time + ts;
    DateTime now = rtc.now();

    Serial.print(now.unixtime());
    Serial.print(", ");
    Serial.println(build_time.unixtime());

    if (abs(now.unixtime() - build_time.unixtime()) > 60) {
        Serial.print("Adjusting the time: ");
        print_time(build_time, true);

        rtc.adjust(build_time);
    }
#endif

#if USE_DS3231
    rtc.writeSqwPinMode(DS3231_SquareWave1Hz);
#elif USE_DS1307
    rtc.writeSqwPinMode(DS1307_SquareWave1HZ);
#endif

    dt = rtc.now();
    print_time(dt, true);

    // blank the display
    digit_0 = -1;
    digit_1 = -1;
    digit_2 = -1;
    digit_3 = -1;
    digit_4 = -1;
    digit_5 = -1;

    // These don't need to be set to zero to blank, the -1 digit value
    // blanks the whole tube. But the code might as well start out with
    // rational values.
    d0_rhdp = 0;
    d1_rhdp = 0;
    d2_rhdp = 0;
    d3_rhdp = 0;
    d4_rhdp = 0;
    d5_rhdp = 0;

    // State machine initial conditions:
    // start up as if the display has cycled once through already
    blanking = true;
    digit = 0; // FIXME Should be zero? 1/9/23

    ambient_light_setup();

    // Set up Timer2 so the PWN on pin 3 uses 32kHz. Also sets up the PID controller
    // parameters.
    hv_ps_setup();

    cli(); // stop interrupts

    // This is used for the 1Hz pulse from the clock that triggers
    // time updates.
    pinMode(CLOCK_1HZ, INPUT_PULLUP);

    // time_1Hz_tick() sets a flag that is tested in loop()
    attachInterrupt(digitalPinToInterrupt(CLOCK_1HZ), timer_1HZ_tick_ISR, RISING);

    // MODE_SWITCH is D3, external 1k pull down
    pinMode(MODE_SWITCH, INPUT);
    attachPCINT(digitalPinToPCINT(MODE_SWITCH), mode_switch_push, RISING);

    // INPUT_SWITCH is D4, external 1k pull down
    pinMode(INPUT_SWITCH, INPUT);
    attachPCINT(digitalPinToPCINT(INPUT_SWITCH), input_switch_push, RISING);

    // Set up timer 2 - controls the display multiplexing

    // set timer2 interrupt at 950uS. Toggles between 950 and 50 uS
    TCCR2A = 0; // set entire TCCR2A register to 0
    TCCR2B = 0; // same for TCCR0B
    TCNT2 = 0;  // initialize counter value to 0

    // set compare match register for 900uS increments
    OCR2A = brightness_count[0]; // = [(16*10^6 / 64 ) * 0.000 900] - 1; (must be <256)

    // turn on CTC mode
    TCCR2A |= _BV(WGM21); // (1 << WGM21)
    // Set CS22 bit for 64 pre-scaler --> B00000100
    TCCR2B |= _BV(CS22); // (1 << CS22)
    // enable timer compare interrupt
    TIMSK2 |= _BV(OCIE2A); // (1 << OCIE2A)

    sei(); // start interrupts
}

void main_mode_handler() {
    static TimeSpan ts(1); // a one-second time span

    if (get_time) {
        get_time = false;
        dt = rtc.now(); // This call takes about 1ms
        update_display_using_mode();
        ambient_light_adjust();
    } else if (update_display) {
        update_display = false;
        dt = dt + ts;                // Advance 'dt' by one second
        update_display_using_mode();
    }
}

void loop() {
    hv_ps_adjust();

    if (poll_mode_button())
        process_mode_switch_press();

    if (poll_input_button())
        process_input_switch_press();
    if (input_switch_held_down())
        process_input_switch_held();

    if (mode == main) {
        main_mode_handler();
    } else if (mode == set_date_time) {
        set_date_time_mode_handler();
    }
}

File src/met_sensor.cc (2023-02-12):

#include <Arduino.h>

#include "met_sensor.h"
#include "print.h"

Adafruit_BME280 bme; // I2C

extern void print(const char *fmt, ...);
extern void print_digits(bool newline);

// The current display digits
extern volatile int digit_0;
extern volatile int digit_1;
extern volatile int digit_2;
extern volatile int digit_3;
extern volatile int digit_4;
extern volatile int digit_5;

extern volatile int d0_rhdp;
extern volatile int d1_rhdp;
extern volatile int d2_rhdp;
extern volatile int d3_rhdp;
extern volatile int d4_rhdp;
extern volatile int d5_rhdp;

extern void blank_dp(); // defined in four_digits.cc

bool init_bme280() {
    // default settings
    bool status = bme.begin(0x76);
    // You can also pass in a Wire library object like &Wire2
    // status = bme.begin(0x76, &Wire2)
    if (!status) {
        Serial.println("Could not find a valid BME280 sensor, check wiring, address, sensor ID!");
        Serial.print("SensorID was: 0x");
        Serial.println(bme.sensorID(), 16);
    }

    return status;
}

void test_bme280() {
    float pressure = bme.readPressure() / 100.0F;
    float altitude = bme.readAltitude(SEALEVELPRESSURE_HPA);
    float temperature = bme.readTemperature();
    float humidity = bme.readHumidity();

    print(F("------------------------------------\n"));
    print(F("Pressure:    %d.%02d hPa\n"), round(pressure), frac(pressure));
    print(F("Altitude:    %d.%02d m\n"), round(altitude), frac(altitude));

    print(F("Temperature: %d.%02d °C\n"), round(temperature), frac(temperature));
    print(F("Relative humidity: %d.%02d °C\n\n"), round(humidity), frac(humidity));
}

// for altitude correction: 1 hPa decrease per 30 feet above MS
static float station_msl = 5560.0; // feet; could be a config param
static float hPa_station_correction = station_msl / 30.0;

volatile int weather_display_state = 0;

// The weather display is a simple state machine:
// 0,..., N/2 - 1: show temperature, humidity
// N/2, ..., N-1: show pressure
void update_display_with_weather() {

    if (weather_display_state > WEATHER_DISPLAY_DURATION - 1)
        weather_display_state = 0;

    switch (weather_display_state) {
    case 0: {
        float temperature = bme.readTemperature() * 9.0 / 5.0 + 32.0;

        int LHS = (int)temperature;
        int RHS = (int)((temperature - LHS) * 100.0);

        blank_dp();
        digit_0 = RHS / 10;
        d1_rhdp = 1;
        digit_1 = LHS % 10;
        digit_2 = LHS / 10;

        digit_3 = -1;
        digit_4 = -1;
        digit_5 = -1;

        break;
    }

    case 4: {
        float humidity = bme.readHumidity();

        int LHS = (int)humidity;
        int RHS = (int)((humidity - LHS) * 100.0);

        blank_dp();

        digit_0 = RHS / 10;
        d1_rhdp = 1;
        digit_1 = LHS % 10;
        digit_2 = LHS / 10;

        digit_3 = -1;
        digit_4 = -1;
        digit_5 = -1;

        break;
    }

    case 8: {
        float pressure = (bme.readPressure() / 100.0F + hPa_station_correction) * inch_Hg_per_hPa;

        int LHS = (int)pressure;
        int RHS = (int)((pressure - LHS) * 100.0);

        blank_dp();
        digit_0 = RHS % 10;
        digit_1 = RHS / 10;
        d2_rhdp = 1;
        digit_2 = LHS % 10;
        digit_3 = LHS / 10;

        digit_4 = -1;
        digit_5 = -1;

        break;
    }

    default:
        break;
    }

    weather_display_state += 1;
}

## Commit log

2022-10-02 Added code to display a BCD digit and to control anode current
2022-10-03 Added more measurements
    Not sure about the scope voltage measurements
2022-10-07 Addd more info about multiplexing
    100Hz - no increase in tube voltage; decrease Ra to 4.k
    and tube voltage increases from 148v to 155v
2022-10-11 This version uses the DS3231 SQW output at 1Hz to trigger the clock read
2022-10-16 Switched DS3231 library to the Adafruit one
2022-10-16 Fixed the display of minutes...hours (was all seconds
    [four_digits.cc]
2022-10-17 Fixed use of timer2 - now the times are correct.
    Digit on time is 900uS and blanking is 50uS
    [four_digits.cc]
2022-10-18 Streamline the main ISR - avoid changing the TIMER2 CS2n bits.
    [four_digits.cc]
2022-10-19 Added Eagle footprint library
2022-10-20 Swapped out the a promini for the nano and a DS1307 for the DS3231
    Burned up the nano and the DS3231. Also increased the blanking time
    to 100uS.
    [four_digits.cc]
2022-10-23 Works but with lots of jitter
    [four_digits.cc]
2022-10-24 Added symbols
    [CR_59-10_U_ONS.step, nixie-2.kicad_pcb, nixie-2.kicad_sch]
2022-10-30 Added files for a PCB
    [nixie-2.kicad_sch]
2022-10-30 Switch to DS3231
2022-10-30 Fixed uodate off by one error
    [four_digits.cc]
2022-11-01 Added mode switch initial version
2022-11-01 Fixed the mode switch code
    [four_digits.cc]
2022-11-01 Mode switch changes
2022-11-01 Added INPUT MODE Switch
2022-11-01 input switch ISRs
2022-11-01 input switch fixes
2022-11-01 Fixes for the inout switch
2022-11-02 Another try at debouncing the input switch
2022-11-02 Time & Date mode - date years are wrong
    [four_digits.cc]
2022-11-02 fix the year 10's digit
    [four_digits.cc]
2022-11-02 More updates
    Changes to prevent display flash on boot didn't work.
    [four_digits.cc]
2022-11-03 Factor DHT sensor code out
2022-11-05 Added MPL3115A2 for barometric pressure info
2022-11-05 Interrupts are stopped while reading from MPL3115A2 - FAIL
    [four_digits.cc]
2022-11-05 Fix interrupts issue for MPL3115A2 - maybe other stuff
    [four_digits.cc]
2022-11-05 Fixes for the weather display
    Increased on time to 4s for each of temp/rh and pressure
    [four_digits.cc]
2022-11-05 Various updates for the pressure display
2022-11-05 Altitude correction for pressure measurement
2022-11-08 Added picture of voltage over Ra
2022-11-09 symbols and footprints
    [nixie-2.kicad_sch]
2022-11-10 New Z570M Footprint
2022-11-11 Mode switch maddness
2022-11-12 Changed buttons to active high with pull down res
2022-11-13 Ignore stuff in PCB for now
2022-11-14 Fix for the DHT sensor failure to read issue
    [four_digits.cc]
2022-11-16 change interrupt to pin 5
2022-11-16 more interrupt change
2022-11-17 Need the 'new' nano bootloader for these knockoff nano boards
2022-11-19 DP fixes ans hacks
    blinks during date, used for weather
    [four_digits.cc]
2022-11-20 Added brightness control
    Use the input button in the main mode to cycle the five levels of
    brightness
2022-11-20 Added new print code files
2022-11-20 New print-fix branch
    The original one did not work.
    [six_digits.cc]
2022-11-21 print and debug macors handle F()
2022-11-21 Compile option to remove DHT22 sensor
2022-11-23 More print fixes
2022-11-24 Reset the timer2 counter to zero in the ISR
    This improves the flicker, but does not fix it.
    Also did more work on the debug printing.
    Removed the DHT22.
    [six_digits.cc]
2022-11-27 Uses timer 1 for multiplexing
2022-11-27 Timer 1 works.
    Debugging the dim display flicker.
2022-11-28 printf for floats
2022-12-03 Added Z573M-tube Schematic and PCB
    [Z573M-tube.kicad_pcb, Z573M-tube.kicad_sch]
2022-12-03 Cleaning house
    [nixie-2.kicad_pcb, nixie-2.kicad_sch]
2022-12-08 Added fork of br3ttb/Arduino-PID-Library
2022-12-09 Removed lame attempt to use my PID library fork.
    Now use the lib/fork via a submodule in the lib dir.
2022-12-09 Removed the PCB dir
    [CR_59-10_U_ONS.step, Z573M-tube.kicad_pcb, Z573M-tube.kicad_sch]
2022-12-21 Added Z573M PCB
    [Z573M-tube.kicad_pcb, Z573M-tube.kicad_sch]
2022-12-21 Pads and design rules
    [Z573M-tube.kicad_pcb]
2023-01-01 New board, v 2.0, with gerber files
    [Z573M-tube-B_Cu.gbr, Z573M-tube-B_Mask.gbr, Z573M-tube-B_Paste.gbr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]
2023-01-12 Info about timer pins
2023-01-12 PCB updates for Z573M breakout
2023-01-13 Z573M PCB files added
2023-01-15 moved digit 0 to pin 7, opens up pin 10 for HV PS PWM
2023-01-15 Added Timer 1 code back into the hv_ps.cc file; commented out for now.
2023-01-15 Fix the timer interrupt for this version
    [six_digits.cc]
2023-01-16 Fixes for the timer switch. Display now refreshes at 160Hz
    [hv_ps.cc, six_digits.cc]
2023-01-16 HV_PS PWN pin now works
2023-01-31 Fixed the pressure calculation
    [met_sensor.cc]
2023-02-01 Added ambient light sensor. Conflicts with the input switch setting.
2023-02-11 Removed interrupt off/on that broke the mode buttons
2023-02-11 Added new function to clear the mode & input switch state
2023-02-11 Refactor how the mode switch state is computed.
2023-02-11 WIP: the input switch
2023-02-12 input switch refactor
2023-02-12 set input_switch_down_time to now, not zero when the button is released.
2023-02-12 Use the pin level, not the interrupt. Assume interrupts might not be correct.
2023-02-12 Removed unused input switch bools
2023-02-12 Removed #if 0 and fixed DST_offset.cc
    [hv_ps.cc, met_sensor.cc]
2023-04-24 Added PCB work
    [nixie-2.1.kicad_pcb, nixie-2.1.kicad_sch, nixie_2_ps.kicad_sch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]
2023-04-24 Update version info on board
    [nixie-2.1.kicad_pcb]
2023-04-25 PCB Stuff
2023-05-10 New display-only board
    [Z573M-display.kicad_pcb, Z573M-display.kicad_sch, nixie-2.1.kicad_pcb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]
2023-05-13 Horizontal pins
    [Z573M-display.kicad_pcb, Z573M-display.kicad_sch]
2023-05-13 Updated PCB with horizontal pin headers and better footprint silkscreens
    [Z573M-display.kicad_pcb]
2023-06-06 updated z573M-logic - try using the zip version
    [Z573M-display.kicad_pcb, nixie_2_ps.kicad_sch]
2023-08-22 Added power board
    [Z573M-power.kicad_pcb, Z573M-power.kicad_sch]
2023-08-22 Display and logic board edits
    [Z573M-display.kicad_pcb, Z573M-display.kicad_sch]
2023-08-22 Added QR code for power board
2023-08-22 Added QR code to power board
    [Z573M-power.kicad_pcb]
2023-08-22 Added nixie-footprints-pretty
2023-08-23 Updated some traces
    [Z573M-power.kicad_pcb]
2023-08-31 Added the Z573M power BOM
    [Z573M-power-BOM.csv]
2023-10-05 Added enclosure and updates to the HV PS
    [Z573M-power.kicad_pcb, box_2.FCStd]
2024-08-31 Fixed hv_ps.cc comments which were for an older version of controller
    [hv_ps.cc, six_digits.cc]

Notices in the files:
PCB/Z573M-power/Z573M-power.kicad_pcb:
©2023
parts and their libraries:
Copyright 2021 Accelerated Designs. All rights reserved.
